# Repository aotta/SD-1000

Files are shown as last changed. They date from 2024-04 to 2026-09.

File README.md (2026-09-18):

# SD-1000
Sega flash multicart for SC-3000, SG-1000 and Mark III based on Pico Clone

SD-1000 is a multicart DIY yourself based on cheap "purple" Raspberry Pi Pico clone.

**WARNING!** "purple" Pico has not the same pinout of original Raspberry "green" ones, you MUST use the clone or you may damage your hardware.

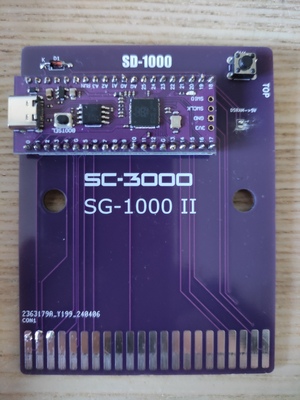
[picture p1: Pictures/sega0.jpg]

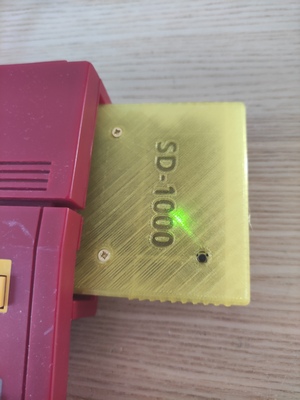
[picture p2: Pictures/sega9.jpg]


Kicad project and gerbers files for the pcb are in the PCB folder, you need only a diode and a push buttons. The jumper for 5V to B3 must left open.
Add you pico clone, and flash the firmware SD1000_cart.uf2 in the Pico by connecting it while pressing button on Pico and drop it in the opened windows on PC.
After flashed with firmware, and every time you have to change your ROMS repository, you can simpli connect the Pico to PC and drag&drop "BIN","ROM","SG","SC" or "SMS" files into.

Even if the diode should protect your console, **DO NOT CONNECT PICO WHILE INSERTED IN A POWERED ON CONSOLE!**

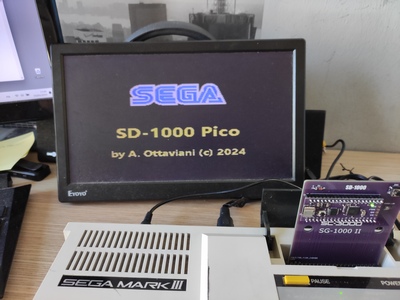
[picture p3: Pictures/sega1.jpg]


## NOTE:
I added v. 1.01 which fixes Ninja Princess and Golgo for SC-3000, and last v.1.02 that works with SG-1000 and Mark III. If you have only the SC-3000, i suggest you use the 1.01 FW

18/09/26 I moved to Arduino IDE, and made v.1.03 that should be more compatible with games but Mark III no more supported. WARNING: if you flash this version from a previous one, you must RE-FORMAT flash and re-upload games

## Credits
I have to thanks some friends for helping me in completing this projects in few time:

Thank to Robin Robin Edwards and his A8PicoCart (https://github.com/robinhedwards/A8PicoCart), i found very smart his way to manage the Flash RAM and the USB updates, so i admit i took large parte of his code for it!.

I used also the new and fantastic CVBasic for writing menu and file selector in Sega, thank to Oscar Toledo (https://nanochess.org/) for creating it and supporting me in an issue with SC-3000.

And, last but not least, a special thank to my friend Fabio (https://github.com/fabiodl) that from Japan leaded me out of a couple of tricky steps.

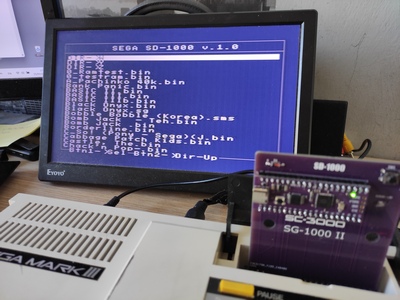
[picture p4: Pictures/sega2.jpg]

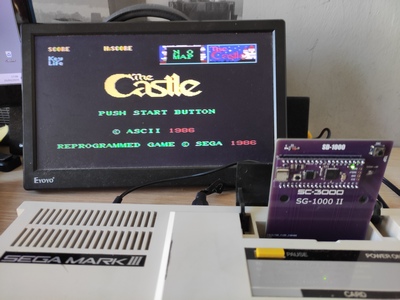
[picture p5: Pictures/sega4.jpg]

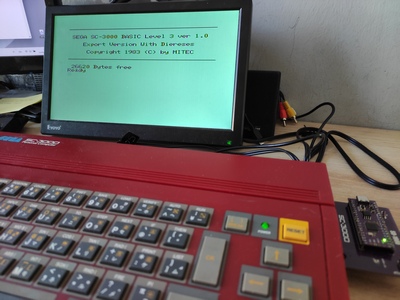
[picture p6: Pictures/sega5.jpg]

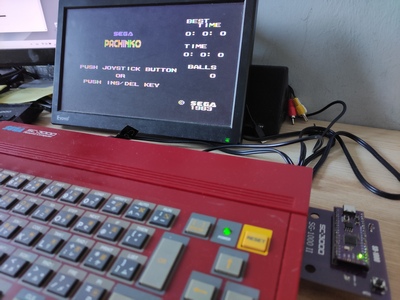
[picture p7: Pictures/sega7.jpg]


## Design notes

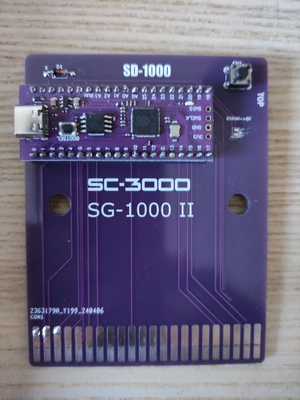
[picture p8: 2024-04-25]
Pictures/sega00.jpg

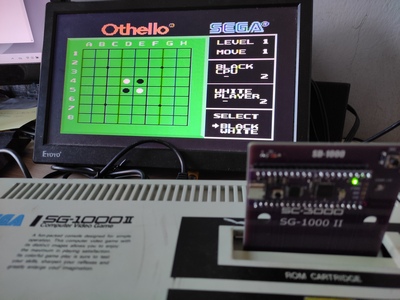
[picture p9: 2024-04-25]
Pictures/sega8.jpg

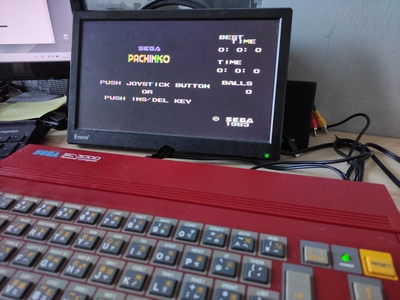
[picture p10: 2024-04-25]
Pictures/sega6.jpg

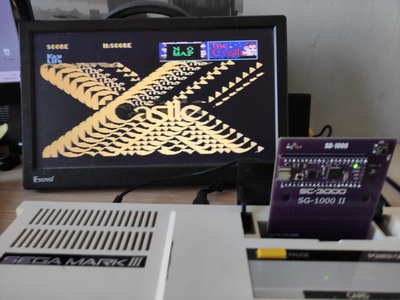
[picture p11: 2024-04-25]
Pictures/sega3.jpg

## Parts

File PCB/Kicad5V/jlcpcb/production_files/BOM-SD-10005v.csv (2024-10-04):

Designator | Footprint | Quantity | Value | LCSC Part #
CON1 | CartridgeEdge | 1 | SC3000-Edge
D1 | D_DO-35_SOD27_P7.62mm_Horizontal | 1 | Diode
J1, J2 | PinSocket_1x20_P2.54mm_Vertical | 2 | Conn_01x20
JP1 | SolderJumper-2_P1.3mm_Open_Pad1.0x1.5mm | 1 | 5v
SW1 | SW_PUSH_6mm | 1 | SW_Push

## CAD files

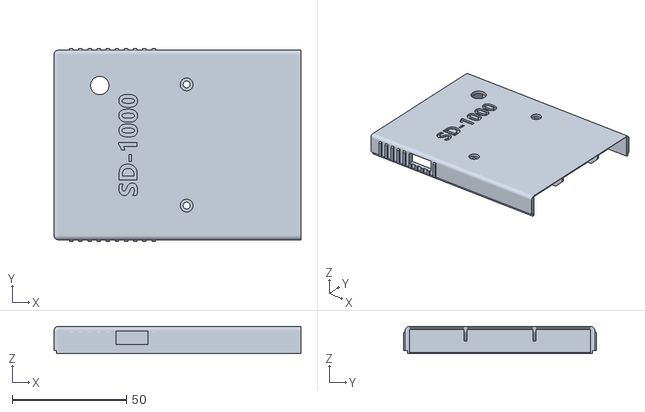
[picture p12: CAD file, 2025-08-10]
3D Model/SD-1000/SD-1000-Top.stl
108.0 x 84.4 x 12.0

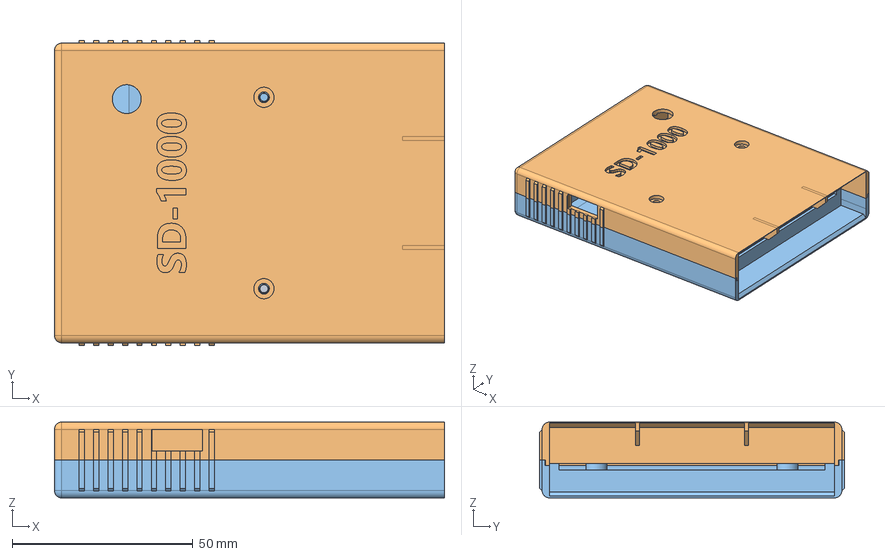
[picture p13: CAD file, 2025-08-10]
3D Model/SD-1000/SD-1000.FCStd
108.0 x 84.4 x 21.0 mm
Top
Bottom

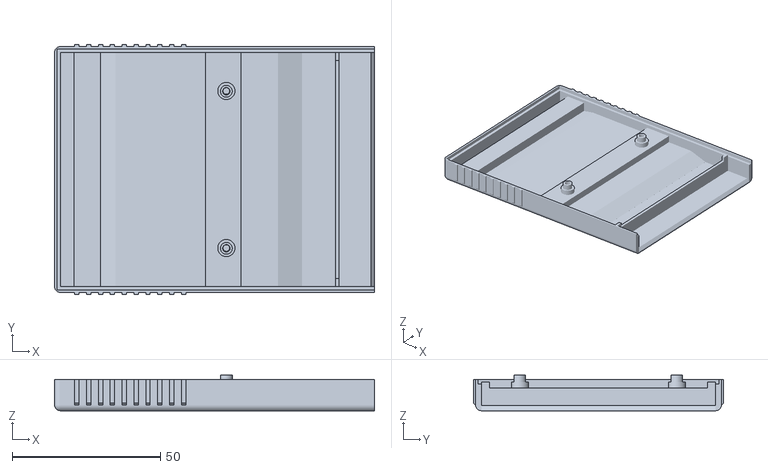
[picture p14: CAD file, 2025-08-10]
3D Model/SD-1000/SD-1000-Bottom.stl
108.0 x 84.4 x 12.0

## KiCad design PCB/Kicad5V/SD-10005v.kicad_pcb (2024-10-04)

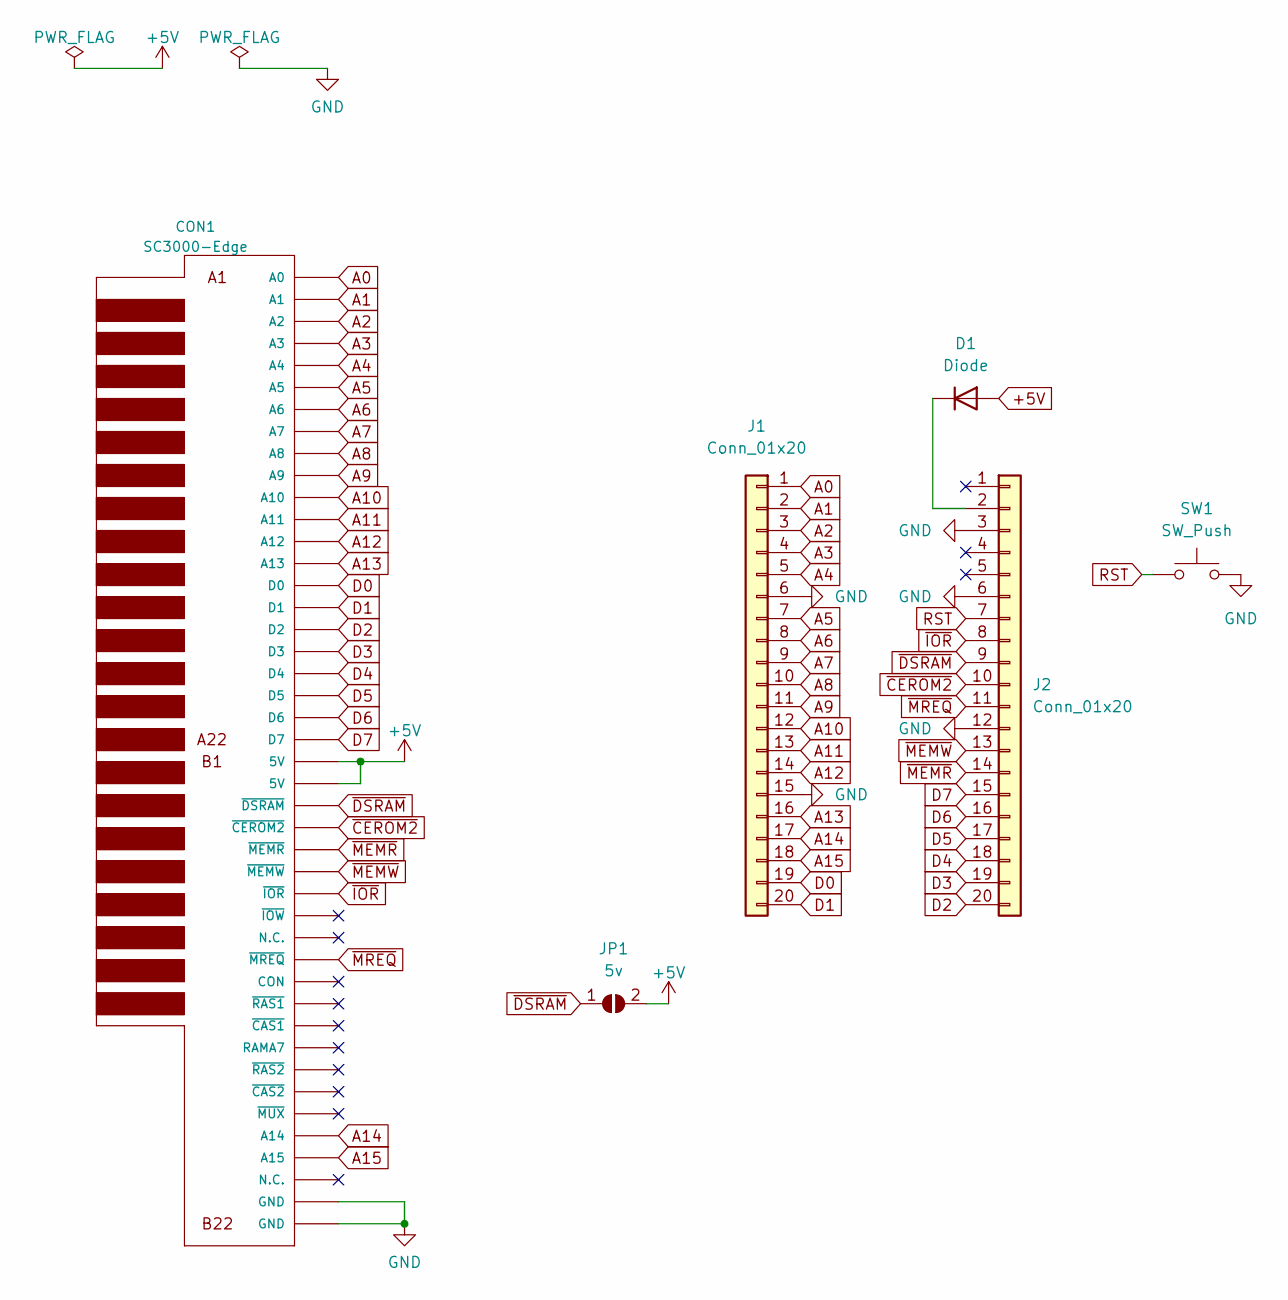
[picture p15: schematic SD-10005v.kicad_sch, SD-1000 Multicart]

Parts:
CON1: SC3000-Edge; CartridgeEdge
D1: Diode; D_DO-35_SOD27_P7.62mm_Horizontal
J1, J2: Conn_01x20; PinSocket_1x20_P2.54mm_Vertical
JP1: 5v; SolderJumper-2_P1.3mm_Open_Pad1.0x1.5mm
SW1: SW_Push; SW_PUSH_6mm

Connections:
+5V: CON1.B1 (5V), CON1.B2 (5V), D1.2 (A), JP1.2 (B)
A0: CON1.A1 (A0), J1.1
A1: CON1.A2 (A1), J1.2
A2: CON1.A3 (A2), J1.3
A3: CON1.A4 (A3), J1.4
A4: CON1.A5 (A4), J1.5
A5: CON1.A6 (A5), J1.7
A6: CON1.A7 (A6), J1.8
A7: CON1.A8 (A7), J1.9
A8: CON1.A9 (A8), J1.10
A9: CON1.A10 (A9), J1.11
A10: CON1.A11 (A10), J1.12
A11: CON1.A12 (A11), J1.13
A12: CON1.A13 (A12), J1.14
A13: CON1.A14 (A13), J1.16
A14: CON1.B18 (A14), J1.17
A15: CON1.B19 (A15), J1.18
D0: CON1.A15 (D0), J1.19
D1: CON1.A16 (D1), J1.20
D2: CON1.A17 (D2), J2.20
D3: CON1.A18 (D3), J2.19
D4: CON1.A19 (D4), J2.18
D5: CON1.A20 (D5), J2.17
D6: CON1.A21 (D6), J2.16
D7: CON1.A22 (D7), J2.15
GND: CON1.B21 (GND), CON1.B22 (GND), J1.6, J1.15, J2.3, J2.6, J2.12, SW1.2
unnamed: D1.1 (K), J2.2
RST: J2.7, SW1.1
~CEROM2: CON1.B4 (~CEROM2), J2.10
~DSRAM: CON1.B3 (~DSRAM), J2.9, JP1.1 (A)
~IOR: CON1.B7 (~IOR), J2.8
~MEMR: CON1.B5 (~MEMR), J2.14
~MEMW: CON1.B6 (~MEMW), J2.13
~MREQ: CON1.B10 (~MREQ), J2.11

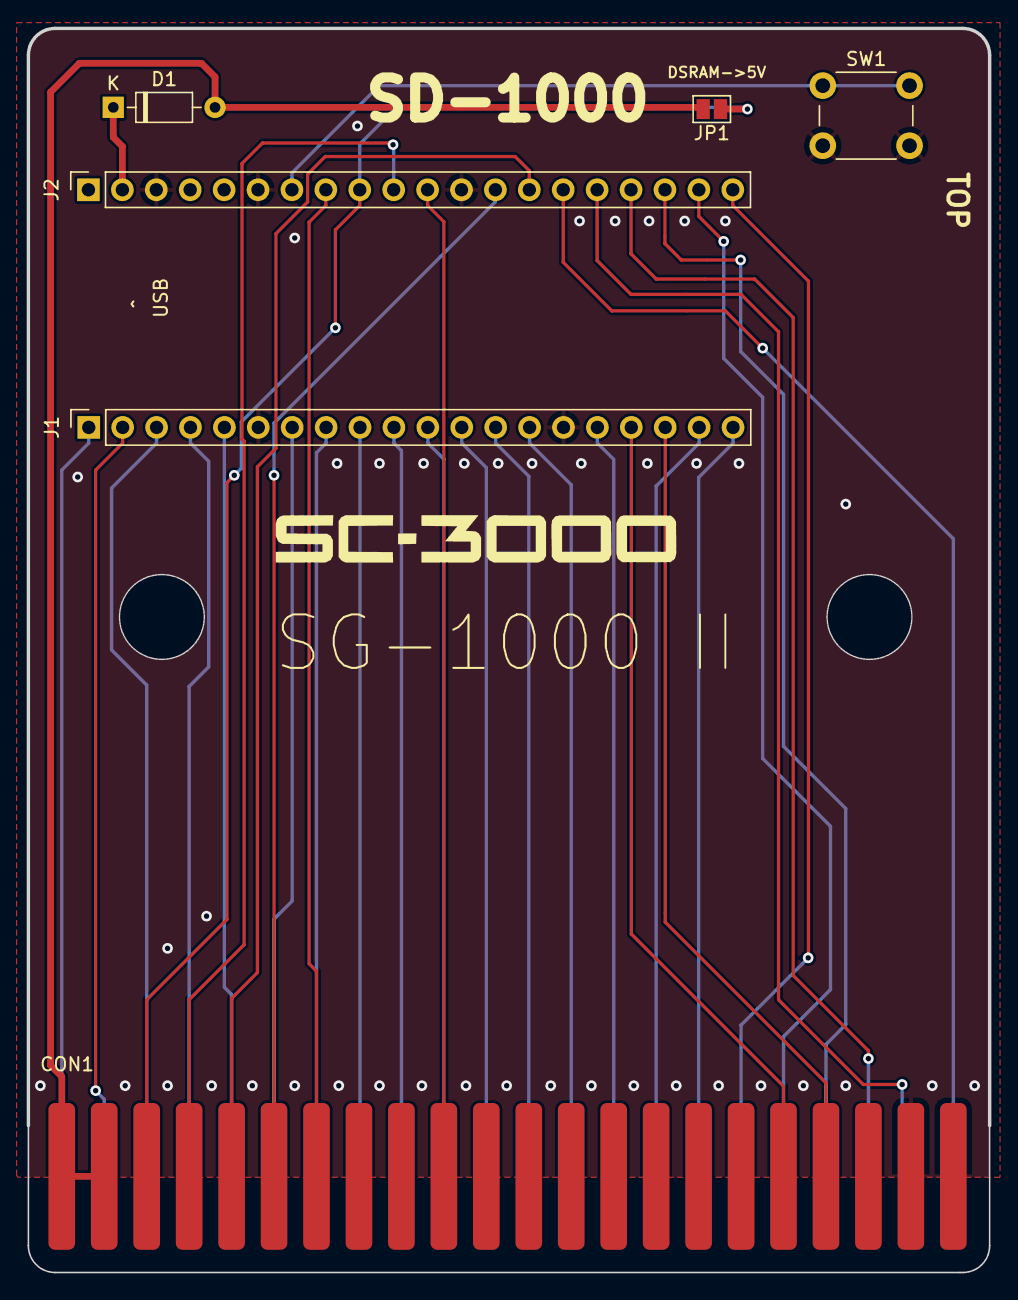
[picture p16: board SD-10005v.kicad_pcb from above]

Board: 2 copper layers, 72.0 x 93.2 mm, 6 parts (0 on the bottom side), 34 nets.

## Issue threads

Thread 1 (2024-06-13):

SD-1000 can't working on SMS

hpx1984, 2024-06-13:
Hi Sir Aotta

i built one set and seems every thing is good (programing pico board and upload ROM all are success)
but it can't working on sega SMS console （both of sg-1000 or SMS ROM into the PICO board），my SMS console will auto run the original game
please help to comment if any thing i can do?
many thanks your great project and help

aotta, 2024-06-13:
The card is for sg-1000, sc-3000 and Mk-III only, SMS has a different pinout

aotta, 2024-06-13:
Not an issue, project is not for SMS system

hpx1984, 2024-06-13:
many thx your comment Sir Aotta
seems my friend provided wrong information to me , he said SG-1000 game card can use on SMS

aotta, 2024-06-13:
I think it's possible on Japanese version of SMS, not the EU or US ones,
because of the different pinout.

Il giorno gio 13 giu 2024 alle ore 16:00 hpx1984 ***@***.***>
ha scritto:

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

hpx1984, 2024-06-13:
Hi Sir Aotta

i think so too , i found some information ot he game card pin layout and seems some one already created the converter
i try to study it and try to build one ,but im not sure whether i can success
https://www.smspower.org/forums/16811-ThanksToThisSiteFinallyMadeAWorkingMarkIIISMSConverter

Closed 2024-06-13.

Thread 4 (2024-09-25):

Official raspberry pico support

lazaj, 2024-09-25:
Nowadays Purple pico are hard to find.
It would be great to update your project to support standard Pico board.

I can help you, all I need is the schematics of purple pico.

aotta, 2024-09-25:
Official Pico haven't enough flash ram neither enough Gpios to work

Closed 2024-09-25.

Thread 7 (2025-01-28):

Original Schematics

buggii, 2025-01-28:
Ciao Andrea,

scusa il disturbo ma non riesco a trovare gli schemi dell'hardware originale (https://github.com/ZX-80/PicoVideocart), sembrano essere stati rimossi dal suo github, tu per caso li hai da poter condividere ?

aotta, 2025-01-28:
No, sorry but the schematics folder was already missing when i discovered the original project. You should open an issue on ZX-80's PicoVideocart repo if you need them

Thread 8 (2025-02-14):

what kind of diode and switch do I need?

jd213, 2025-02-14:
Hi, can you specify the type/values for the diode and switch needed for this project?  The BOM doesn't seem very specific.

aotta, 2025-02-14:
i use 1n4148 or 1n5817, but any schottky diode with low consumption should work fine

Closed 2025-02-14.

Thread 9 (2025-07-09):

PICO Cart with memory

pocoaust, 2025-07-09:
G'day mate,

Thanks for your work, i got a SC-3000h without anything, and after fixing the video board was able to boot off your pico Cart to test the little bugger.

I was wondering about adding a CY62256 to the design to add the extra memory by default.  There seems to be plenty of real estate
on the PCB.

There is a copy of the Basic Cart on PCBway, but no schematic.

https://www.pcbway.com/project/shareproject/SC_3000_Sega_Basic_Level_IIIA_e54cd768.html

Would this be a simple matter?

Any thoughts?

Thanks
Paul in Australia

Closed 2025-07-09.

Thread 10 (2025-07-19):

Cartridge STL

FabfMSX, 2025-07-19:
Hi
There is an issue with the cartridge STL.
3 or 4 mm are missing then the PCB can’t plug in a top cartridge slot.
In a real cartridge the PCB must flush with the cartridge edge.
Regards
Fabrice

aotta, 2025-08-10:
You're right, I'm going to revise the stl

aotta, 2025-08-10:
Uploaded revised STL

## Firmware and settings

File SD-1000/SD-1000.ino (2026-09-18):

/*
//                       SD-1000 MultiCART by Andrea Ottaviani 
// SEGA SC-3000 - SG-1000  multicart based on Raspberry Pico board -

// v. 1.0 2024-03-26 : Initial version for Pi Pico 
//
// 
//  More info on https://github.com/aotta/ 
*/

#include "hardware/gpio.h"
#include "pico/platform.h"
#include "pico/stdlib.h"
#include "hardware/vreg.h"
#include "pico/multicore.h"
#include "hardware/flash.h"
#include "hardware/sync.h"
#include "string.h"
#include "splash.h"

#include "dir_entry.hpp"
// include for Flash files
#include "SdFat_Adafruit_Fork.h"
#include "Adafruit_SPIFlash.h"
#include "Adafruit_TinyUSB.h"

Adafruit_FlashTransport_RP2040 flashTransport;
Adafruit_SPIFlash flash(&flashTransport);

FatVolume fatfs;
File32 root;
File32 file;
File32 romFile;

Adafruit_USBD_MSC usb_msc;
bool fs_formatted;
bool fs_changed = false;


// Pico pin usage definitions

#define A0_PIN    0
#define A1_PIN    1
#define A2_PIN    2
#define A3_PIN    3
#define A4_PIN    4
#define A5_PIN    5
#define A6_PIN    6
#define A7_PIN    7
#define A8_PIN    8
#define A9_PIN    9
#define A10_PIN  10
#define A11_PIN  11
#define A12_PIN  12
#define A13_PIN  13
#define A14_PIN  14
#define A15_PIN  15
#define D0_PIN   16
#define D1_PIN   17
#define D2_PIN   18
#define D3_PIN   19
#define D4_PIN   20
#define D5_PIN   21
#define D6_PIN   22
#define D7_PIN   23
#define MEMR_PIN  24
#define MEMW_PIN  25
#define MREQ_PIN  26
#define CEROM2_PIN  27
#define DSRAM_PIN  28 
#define IOR_PIN  29 

// Pico pin usage masks

#define A0_PIN_MASK     0x00000001L
#define A1_PIN_MASK     0x00000002L
#define A2_PIN_MASK     0x00000004L
#define A3_PIN_MASK     0x00000008L
#define A4_PIN_MASK     0x00000010L
#define A5_PIN_MASK     0x00000020L
#define A6_PIN_MASK     0x00000040L
#define A7_PIN_MASK     0x00000080L
#define A8_PIN_MASK     0x00000100L
#define A9_PIN_MASK     0x00000200L
#define A10_PIN_MASK    0x00000400L
#define A11_PIN_MASK    0x00000800L
#define A12_PIN_MASK    0x00001000L
#define A13_PIN_MASK    0x00002000L
#define A14_PIN_MASK    0x00004000L
#define A15_PIN_MASK    0x00008000L
#define D0_PIN_MASK     0x00010000L
#define D1_PIN_MASK     0x00020000L
#define D2_PIN_MASK     0x00040000L
#define D3_PIN_MASK     0x00080000L
#define D4_PIN_MASK     0x00100000L
#define D5_PIN_MASK     0x00200000L  // gpio 21
#define D6_PIN_MASK     0x00400000L
#define D7_PIN_MASK     0x00800000L

#define MEMR_PIN_MASK   0x01000000L //gpio 24
#define MEMW_PIN_MASK   0x02000000L
#define MREQ_PIN_MASK   0x04000000L  //gpio 26
#define CEROM2_PIN_MASK 0x08000000L
#define DSRAM_PIN_MASK  0x10000000L
#define IOR_PIN_MASK    0x20000000L

// Aggregate Pico pin usage masks
#define ALL_GPIO_MASK  	0x3FFFFFFFL
#define BUS_PIN_MASK    0x0000FFFFL
#define DATA_PIN_MASK   0x00FF0000L
#define FLAG_MASK       0x2F000000L
//#define ROM_MASK ( MREQ_PIN_MASK  ) // | MREQ_PIN_MASK | MEMR_PIN_MASK A15_PIN_MASK |
#define ROM_MASK ( MREQ_PIN_MASK  | MREQ_PIN_MASK | MEMR_PIN_MASK | A15_PIN_MASK)
#define ALWAYS_IN_MASK  (BUS_PIN_MASK | FLAG_MASK)

#define SET_DATA_MODE_OUT   gpio_set_dir_out_masked(DATA_PIN_MASK)
#define SET_DATA_MODE_IN    gpio_set_dir_in_masked(DATA_PIN_MASK)
// We're going to erase and reprogram a region 256k from the start of flash.
// Once done, we can access this at XIP_BASE + 256k.


char RBLo,RBHi;
#define BINLENGTH  65536L
unsigned char ROM[BINLENGTH];
unsigned char game[BINLENGTH];
unsigned char files[256*256] = {0};
unsigned char nomefiles[32*25] = {0};
char curPath[256] = "";
char path[256];
int fileda=0,filea=0;
bool cmd_executing=false;

// Callbacks USB MSC
int32_t msc_read_cb(uint32_t lba, void* buffer, uint32_t bufsize) {
  return flash.readBlocks(lba, (uint8_t*)buffer, bufsize / 512) ? bufsize : -1;
}

int32_t msc_write_cb(uint32_t lba, uint8_t* buffer, uint32_t bufsize) {
  return flash.writeBlocks(lba, buffer, bufsize / 512) ? bufsize : -1;
}

void msc_flush_cb(void) {
  flash.syncBlocks();
  fatfs.cacheClear();
  fs_changed = true;
}


////////////////////////////////////////////////////////////////////////////////////
//                     REBOOT
////////////////////////////////////////////////////////////////////////////////////
void doReboot() {
  rp2040.reboot();
}
////////////////////////////////////////////////////////////////////////////////////
//                     HANDLE BUS
////////////////////////////////////////////////////////////////////////////////////

void __time_critical_func(loop1()) {   //HandleBUS()
  char dataWrite=0;
  uint32_t pins=0;
  uint32_t addr;
  
  // Main loop   
   
  gpio_set_dir_in_masked(ALWAYS_IN_MASK);
  
  // Initial conditions
  SET_DATA_MODE_IN;
    
    
  while (1)
 {
    while ((pins = gpio_get_all()) & MREQ_PIN_MASK ); //removed for compatibility with SG-1000, which doesn't have IOR
   
    pins = gpio_get_all();   // to keep for SG-1000 compatibility, we read the pins again after the wait for MREQ to go low
	
    addr = pins & BUS_PIN_MASK;

    if (!(pins & MEMR_PIN_MASK)) {
        SET_DATA_MODE_OUT;
		    gpio_put_masked(DATA_PIN_MASK, ROM[addr] << 16);  
        // Sync: wait end of read from CPU Z80
        while (!(gpio_get_all() & MEMR_PIN_MASK));  // removed for compatibility with Mark III
        SET_DATA_MODE_IN;
    } 
    else if (!(pins & MEMW_PIN_MASK)) {        
		if ((1)) { //little delay to fix Golgo 13 & Ninja Princess
	    dataWrite = ((gpio_get_all() & DATA_PIN_MASK) >> 16);
      ROM[addr] = dataWrite;
      // Sync: wait end of write from CPU Z80
			while (!(gpio_get_all() & MEMW_PIN_MASK)); 
		}
	}
 }
}
////////////////////////////////////////////////////////////////////////////////////
//                     RESET SEGA
////////////////////////////////////////////////////////////////////////////////////    
void reset() {
  
  rp2040.idleOtherCore();
  while (!(gpio_get_all() & MEMR_PIN_MASK));
  SET_DATA_MODE_OUT;
  gpio_put_masked(DATA_PIN_MASK,0xc7<<16);
  while (!(gpio_get_all() & MEMR_PIN_MASK));
  SET_DATA_MODE_IN;

   while (!(gpio_get_all() & MEMR_PIN_MASK));
  SET_DATA_MODE_OUT;
  gpio_put_masked(DATA_PIN_MASK,0xc7<<16);
  while (!(gpio_get_all() & MEMR_PIN_MASK));
  SET_DATA_MODE_IN;

  
   while (!(gpio_get_all() & MEMR_PIN_MASK));
  SET_DATA_MODE_OUT;
  gpio_put_masked(DATA_PIN_MASK,0xc7<<16);
  while (!(gpio_get_all() & MEMR_PIN_MASK));
  SET_DATA_MODE_IN;
  rp2040.resumeOtherCore();
}       

////////////////////////////////////////////////////////////////////////////////////
//                     LOAD ROM
////////////////////////////////////////////////////////////////////////////////////
void loadROM(){ 
  String riga;
  int numErr=0;
  
  for(int i=0;i<(sizeof(_actest));i++){
    unsigned int dataW= _actest[i];
    ROM[i]=dataW;
  }
}
////////////////////////////////////////////////////////////////////////////////////
//                     LOAD Game
////////////////////////////////////////////////////////////////////////////////////
void LoadGame(){ 
  int numfile=0;
  int numErr=0;
  int romLen=0;
  char longfilename[32];
  
  char firstbyte=0x0;

    numfile=ROM[50001]+fileda-1;
	DIR_ENTRY *entry = (DIR_ENTRY *)&files[0];
    
	strcpy(longfilename,entry[numfile].long_filename);
    if (entry[numfile].isDir)
	{	// directory
     	strcat(curPath, "/");
		strcat(curPath, entry[numfile].filename);
		ROM[50000]=1; // re-read dir, path is changed
		SEGAMenu(1);
	} else {
		memset(path,0,sizeof(path));
		strcat(path,curPath);
		strcat(path, "/");
		strcat(path,longfilename);
   		for (int i=0;i<sizeof(path);i++) ROM[50002+i]=path[i];
		ROM[50000]=5;
		sleep_ms(540);
  	reset();
    load_file(path);  // load rom in files[]
    //load_file("/B/Bank Panic (JP).sg");
	
   // vreg_set_voltage(VREG_VOLTAGE_1_20); // set to 1_15 or 1_20 if you experience some glitches
   // sleep_ms(10);
   // set_sys_clock_khz(270000, true); // settled in compiler IDE as 250mhz overclocked
  
    reset(); 
   	memcpy(ROM,game,BINLENGTH);
	  
  
    reset(); 
    
    while(1);    
  }  
}

/////////////////////////////// file structures 

int read_directory(char *path) {
  //  if (path[0]==0) strcpy(path,'/');
    Serial.print("Read_directory: ");
    Serial.println(path);
    int ret = 0;
    num_dir_entries = 0;
    DIR_ENTRY *dst = (DIR_ENTRY *)&files[0];

    FatFile dir;
    if (dir.open(path, O_RDONLY)) {
        FatFile file;
        while (num_dir_entries < 99 && file.openNext(&dir, O_RDONLY)) {
            char filename[256];
            file.getName(filename, sizeof(filename));
       //     Serial.println(filename);
            if (strcmp(filename, ".") == 0 || strcmp(filename, "..") == 0) {
                file.close();
                continue;
            }
            
            if (file.isHidden() || file.isSystem()) {
                file.close();
                continue;
            }
            
            dst->isDir = file.isDir();
            if (!dst->isDir && !is_valid_file(filename)) {
                file.close();
                continue;
            }
            
            // Usa lo stesso nome per entrambi i campi
            strncpy(dst->long_filename, filename, 31);
            dst->long_filename[31] = 0;
            strncpy(dst->filename, filename, 24);
            dst->filename[24] = 0;
            
            dst->full_path[0] = 0;
            dst++;
            num_dir_entries++;
            
            file.close();
        }
        dir.close();
        
        qsort((DIR_ENTRY *)&files[0], num_dir_entries, sizeof(DIR_ENTRY), entry_compare);
        ret = 1;
    }
    else {
        Serial.println("Can't read directory");
    }
    
    return ret;
}

/* load file in  ROM */

/////////////////////////////////////////////////////////////////////////////////////////
///////////////////////////////* load file in  ROM */////////////////////////////////////
/////////////////////////////////////////////////////////////////////////////////////////

void load_file(char *filename) {
    Serial.print("load file: ");
    Serial.println(filename);

    if (!(file.open(filename))) {
        Serial.print("Can't open file ");
        Serial.println(filename);
        return;
    }

    // 🔥 AZZERA IL BUFFER PRIMA DI LEGGERE
    memset(game, 0, BINLENGTH);
    
    int n = file.read(game, BINLENGTH);
    Serial.print("Read: ");
    Serial.print(n);
    Serial.println(" bytes");
    file.close();
}


////////////////////////////////////////////////////////////////////////////////////
//                     filelist
////////////////////////////////////////////////////////////////////////////////////

void filelist(DIR_ENTRY* en,int da, int a)
{
  char longfilename[32];

  for(int i=0;i<32*20;i++) ROM[50002+i]=0;
    for(int n = 0;n<(a-da);n++) {
		memset(longfilename,0,32);
	
	 	if (en[n+da].isDir) {
			strcpy(longfilename,"DIR->");
			ROM[51000+n]=1;
			strcat(longfilename, en[n+da].long_filename);
	 	} else {
			ROM[51000+n]=0;
			strcpy(longfilename, en[n+da].long_filename);
	 	}
	 	for(int i=0;i<31;i++) {
      		ROM[50002+i+(n*32)]=longfilename[i];
	  		if ((ROM[50002+i+(n*32)])<=20) ROM[50002+i+(n*32)]=32;
     	}
		strcpy((char*)&nomefiles[32*n], longfilename);
	}
	ROM[51030]=da;ROM[51031]=a;ROM[51032]=num_dir_entries;
  }

////////////////////////////////////////////////////////////////////////////////////
//                     SEGAMenu
////////////////////////////////////////////////////////////////////////////////////
void SEGAMenu(int tipo) { // 1=start,2=next page, 3=prev page, 4=dir up
  int numfile=0;
  int maxfile=0;
  int ret=0;
  int rootpos[255];
  int lastpos;
  //Serial.print("cmd: ");  Serial.println(tipo);	
/////////////////// TIPO 1 /////////////////// 
  	if (tipo==1) {
		ret = read_directory(curPath);
    if (!(ret)) {
        curPath[0]='/';
        curPath[1]=0;
        read_directory(curPath);
        //Serial.println("Dir missed, return root");
        //error(1);
    }
		maxfile=20;
		fileda=0;
		if (maxfile>num_dir_entries) maxfile=num_dir_entries;
		filea=fileda+maxfile;
		filelist((DIR_ENTRY *)&files[0],fileda,filea);
		//sleep_ms(1400);
    } else 
/////////////////// TIPO 2 /////////////////// 
	if ((tipo==2) && (filea<num_dir_entries)) {
		maxfile=20;
		if ((filea+maxfile)>num_dir_entries) maxfile=num_dir_entries-filea;
   		fileda=filea;
		filea=fileda+maxfile;
		filelist((DIR_ENTRY *)&files[0],fileda,filea);
		//sleep_ms(3400);
		
	} else
/////////////////// TIPO 3 /////////////////// 
   	if ((tipo==3) && (fileda>=20)) {
		fileda=fileda-20;
		filea=fileda+20;
		filelist((DIR_ENTRY *)&files[0],fileda,filea);
	
	}
}
////////////////////////////////////////////////////////////////////////////////////
//                     Directory Up
////////////////////////////////////////////////////////////////////////////////////
void DirUp() {
	int len = strlen(curPath);
	if (len>0) {
		while (len && curPath[--len] != '/');
		curPath[len] = 0;
		//while (len && curPath[--len] != '/');
		//curPath[len] = 0;
	}

}
////////////////////////////////////////////////////////////////////////////////////
//                     SETUP
////////////////////////////////////////////////////////////////////////////////////

void setup() {

  //
   
  gpio_init_mask(ALL_GPIO_MASK);
  pinMode(DSRAM_PIN,OUTPUT);
  digitalWrite(DSRAM_PIN,HIGH);

 // Initialize the bus state variables
  
  
  pinMode(CEROM2_PIN,INPUT);
 
 bool carton = false;
  int t = 100;
  
  while (gpio_get(CEROM2_PIN) == 0 && to_ms_since_boot(get_absolute_time()) < 2000) {
    if (to_ms_since_boot(get_absolute_time()) > t) {
      t += 100;
    }
    sleep_ms(1);
  }
  
 if (gpio_get(CEROM2_PIN) == 1) {
    carton = true;  
 }
  
   vreg_set_voltage(VREG_VOLTAGE_1_15); // set to 1_15 or 1_20 if you experience some glitches
  sleep_ms(10);
  set_sys_clock_khz(250000, true); // settled in compiler IDE as 250mhz overclocked

  Serial.begin(115200);
  //while(!Serial);

  
  Serial.println("P-ON your SEGA!");
  

  // Inizializza flash
  flash.begin();
  
  // Configura USB MSC
  usb_msc.setID("SD-1000", "External Flash", "1.0");
  usb_msc.setReadWriteCallback(msc_read_cb, msc_write_cb, msc_flush_cb);
  usb_msc.setCapacity(flash.size() / 512, 512);
  usb_msc.setUnitReady(true);
  usb_msc.begin();
  
  if (TinyUSBDevice.mounted()) {
    TinyUSBDevice.detach();
    sleep_ms(10);
    TinyUSBDevice.attach();
    sleep_ms(10);
  }
  
  // Monta filesystem
  fs_formatted = fatfs.begin(&flash);
  
  if (!carton) {
    // Modalità PC
    usb_msc.setUnitReady(true);
    while (1) {
      gpio_put(25,1);
      delay(100);
      gpio_put(25,0);
      delay(500);
    }
  }
  
  // === MODALITÀ CONSOLE ===
  usb_msc.setUnitReady(false);
  
  memset(ROM,0,BINLENGTH);
  
    loadROM();
   
}
////////////////////////////////////////////////////////////////////////////////////
//                     MAIN LOOP
////////////////////////////////////////////////////////////////////////////////////    
  
void loop() 

{
  int i=0;
  int cmd=0; // start with read files
  // Initialize GPIO pins
   curPath[0]='/';
   curPath[1]=0;
 
  while (1) {
	 cmd_executing=false;
     cmd=ROM[50000];

     if ((cmd>0)&&!(cmd_executing)) {
      switch (cmd) {
      case 1:  // read file list
        cmd_executing=true;
        //sleep_ms(200);
	    ROM[50000]=0;
    	SEGAMenu(1);
	 	ROM[49999]=1;
      	break;
      case 2:  // run file list
        cmd_executing=true;
    	ROM[50000]=0;
	 	LoadGame();
		ROM[49999]=1;
      	break;
      case 3:  // next page
	    sleep_ms(200);
	    cmd_executing=true;
      	ROM[50000]=0;
     	SEGAMenu(2);
		ROM[49999]=1;
      	break;
      case 4:  // prev page
        cmd_executing=true;
      	ROM[50000]=0;
     	SEGAMenu(3);
		ROM[49999]=1;
      	break;
	  case 5:  // up dir
        cmd_executing=true;
      	sleep_ms(200);
	    ROM[50000]=0;
      	DirUp();
		SEGAMenu(1);
		ROM[49999]=1;
      	break;
    }     
   }
  }
  //printLog();
  
  //Serial.println("");
  i=0;
 }

////////////////////////////////////////////////////////////////////////////////////
//                     MAIN LOOP
////////////////////////////////////////////////////////////////////////////////////    
  
void setup1()
{
   
}

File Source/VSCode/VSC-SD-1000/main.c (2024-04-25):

/*
//                       SD-1000 MultiCART by Andrea Ottaviani 2024
//
//  SEGA SC-3000 - SG-1000  multicart based on Raspberry Pico board -
//
//  More info on https://github.com/aotta/ 
//
//   parts of code are directly from the A8PicoCart project by Robin Edwards 2023
//  
//   Needs to be a release NOT debug build for the cartridge emulation to work
// 
//   Edit myboard.h depending on the type of flash memory on the pico clone//
//
//   v. 1.0 2024-03-26 : Initial version for Pi Pico 
//
*/



#include <stdio.h>
#include <string.h>

#include "pico/stdlib.h"
#include "pico/time.h"
#include "tusb.h"

#include "sega_cart.h"
#include "fatfs_disk.h"

//void cdc_task(void);


//--------------------------------------------------------------------+
// USB CDC
//--------------------------------------------------------------------+
void cdc_task(void)
{
  // connected() check for DTR bit
  // Most but not all terminal client set this when making connection
  // if ( tud_cdc_connected() )
  {
    // connected and there are data available
    if ( tud_cdc_available() )
    {
      // read data
      char buf[64];
      uint32_t count = tud_cdc_read(buf, sizeof(buf));
      (void) count;

      // Echo back
      // Note: Skip echo by commenting out write() and write_flush()
      // for throughput test e.g
      //    $ dd if=/dev/zero of=/dev/ttyACM0 count=10000
      tud_cdc_write(buf, count);
      tud_cdc_write_flush();
    }
  }
}

// Invoked when cdc when line state changed e.g connected/disconnected
void tud_cdc_line_state_cb(uint8_t itf, bool dtr, bool rts)
{
  (void) itf;
  (void) rts;

  // TODO set some indicator
  if ( dtr )
  {
    // Terminal connected
  }else
  {
    // Terminal disconnected
  }
}

// Invoked when CDC interface received data from host
void tud_cdc_rx_cb(uint8_t itf)
{
  (void) itf;
}


int main(void)
{
   tusb_init();
   stdio_init_all();   // for serial output, via printf()
   
    tud_init(BOARD_TUD_RHPORT);
    gpio_init(CEROM2_PIN);
    gpio_set_dir(CEROM2_PIN, GPIO_IN);
   
    while(1) {          
      
    while (to_ms_since_boot(get_absolute_time()) < 200)
    {
      if ((gpio_get(CEROM2_PIN)))
        sega_cart_main();
    }

     
       // init device stack on configured roothub port
       // we are presumably powered from USB
       // enter USB mass storage mode
     //  tud_init(BOARD_TUD_RHPORT);
     //  stdio_init_all();   // for serial output, via printf()
     //  printf("Start\n");

       while (1) {
          tud_task(); // tinyusb device task
         
          cdc_task();
       }
    
    }
   return 0;
}

//--------------------------------------------------------------------+
// Device callbacks
//--------------------------------------------------------------------+

// Invoked when device is mounted
void tud_mount_cb(void)
{
  printf("Device mounted\n"); 
  if (!mount_fatfs_disk())
    create_fatfs_disk();
}

// Invoked when device is unmounted
void tud_umount_cb(void)
{
  printf("Device unmounted\n");  
}

// Invoked when usb bus is suspended
// remote_wakeup_en : if host allow us  to perform remote wakeup
// Within 7ms, device must draw an average of current less than 2.5 mA from bus
void tud_suspend_cb(bool remote_wakeup_en)
{
  (void) remote_wakeup_en;
//  blink_interval_ms = BLINK_SUSPENDED;
}

// Invoked when usb bus is resumed
void tud_resume_cb(void)
{
//  blink_interval_ms = BLINK_MOUNTED;
}

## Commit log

2024-04-25 Add files via upload
    Initial realease
    [BOM-SD-10005v.csv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]
2024-04-26 Add files via upload
    bug fixed in cvbasic, rom.h and cvs_basic_prologue.asm updated. Use this patched version (ram and stack map are different) when compiling for SD-1000
    [cvbasic_prologue.asm]
2024-04-27 Add files via upload
    lowered usb hole
    [SD-1000-Top3D.stl, SD-1000.FCStd]
2024-06-03 Add files via upload
    bug fixed for roms greater than 40k
    [sega_cart.c]
2024-10-04 Update PCB
    -- Ground plane added to TOP & BOTTOM layer
    -- Better routing for some tracks
    -- Production files updated
    -- JLCPCB DRU file added
    [BOM-SD-10005v.csv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]
2025-08-10 Re-positioning PCB
    Slided of 3mm PCB for better compatibility with SG-1000
    [SD-1000-Bottom.stl, SD-1000-Top.stl, SD-1000.FCStd]
2026-09-17 fixed SG-1000 / Mark III not booting
    fixed SG-1000 / Mark III not booting
    [sega_cart.c]
2026-09-18 New V.1.03 migrated to Arduino IDE
    New V.1.03 migrated to Arduino IDE
2026-09-18 New Arduino version - Flash must be re-formatted
    New Arduino version - Flash must be re-formatted
